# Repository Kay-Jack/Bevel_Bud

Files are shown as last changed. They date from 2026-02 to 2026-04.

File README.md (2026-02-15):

# Bezel_Bud
Take a webcam -> remove the camera -> improve the microphone.

- **Status:** Prototype Dev Board
- **Author:** Jack Kay

## Features

- **Feature 1:** 48KHz Dual Microphone - TI PCM1861
- **Feature 2:** Low noise components
- **Feature 3:** Power filtering
- **Feature 4:** 24.576MHz Crystal
- **Feature 5:** Mute switch and Visual LED
- **Feature 6:** Configurable jumpers for ADC
- **Feature 7:** USB-C for connectivity
- **Feature 8:** STM32G431CBT6

## Photos

### Assembly PCB

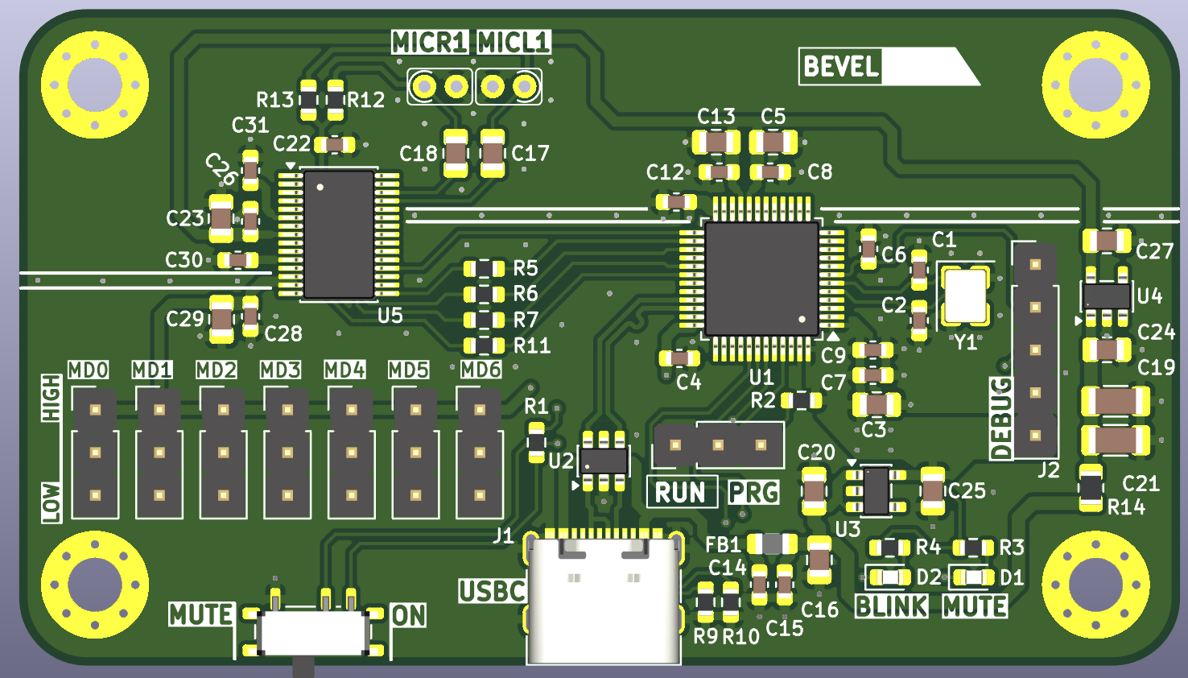
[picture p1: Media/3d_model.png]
3D model


### Layout

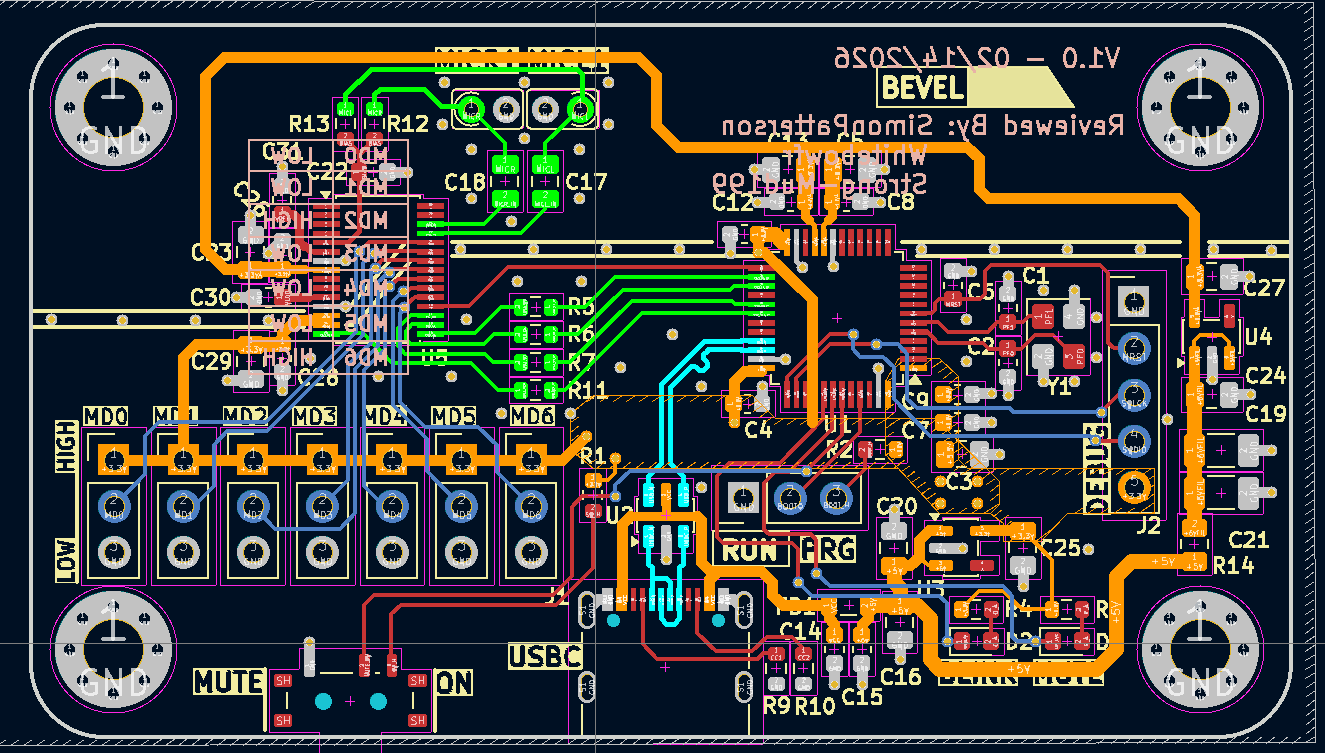
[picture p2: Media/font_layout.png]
Font layout


### Schematic

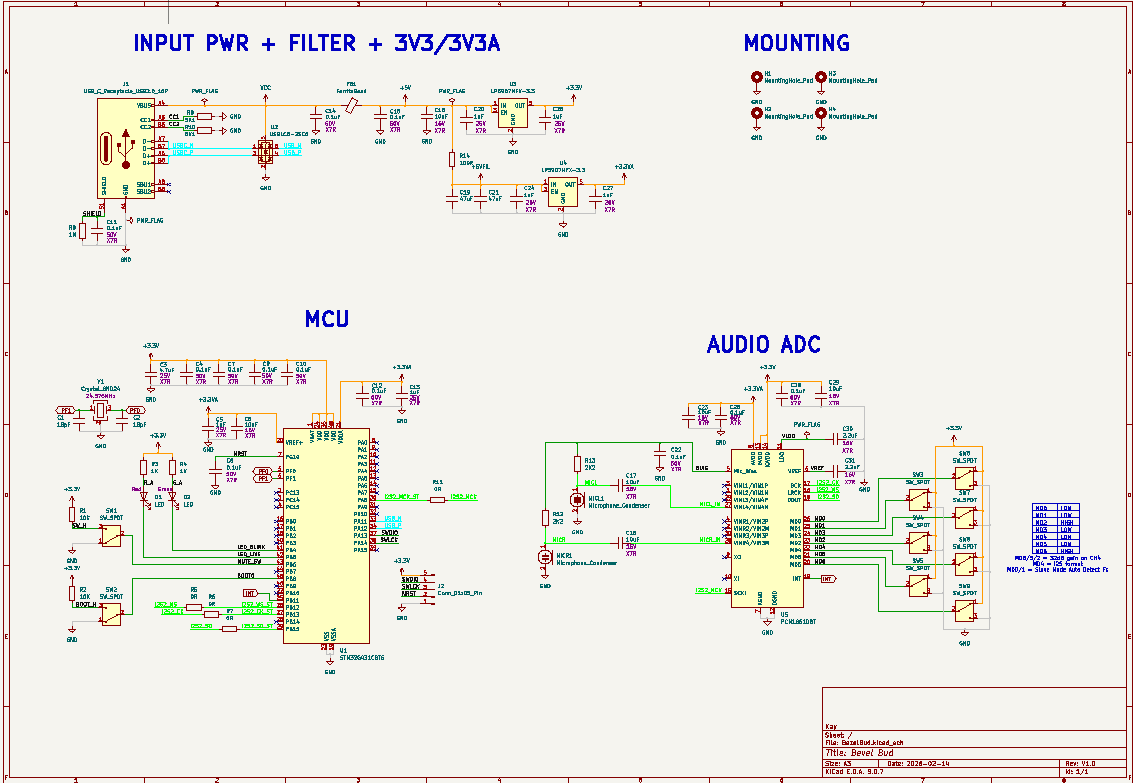
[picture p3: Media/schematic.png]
Schematic


## Firmware / Electronics

[WIP]

## CAD / Mechanical

[WIP]

## Build Instructions

[WIP]

## Usage

[WIP]

## License

This project is licensed under the terms in the `LICENSE` file.

## Contact

Maintainer: Jack Kay — jack.wil.kay@gmail.com

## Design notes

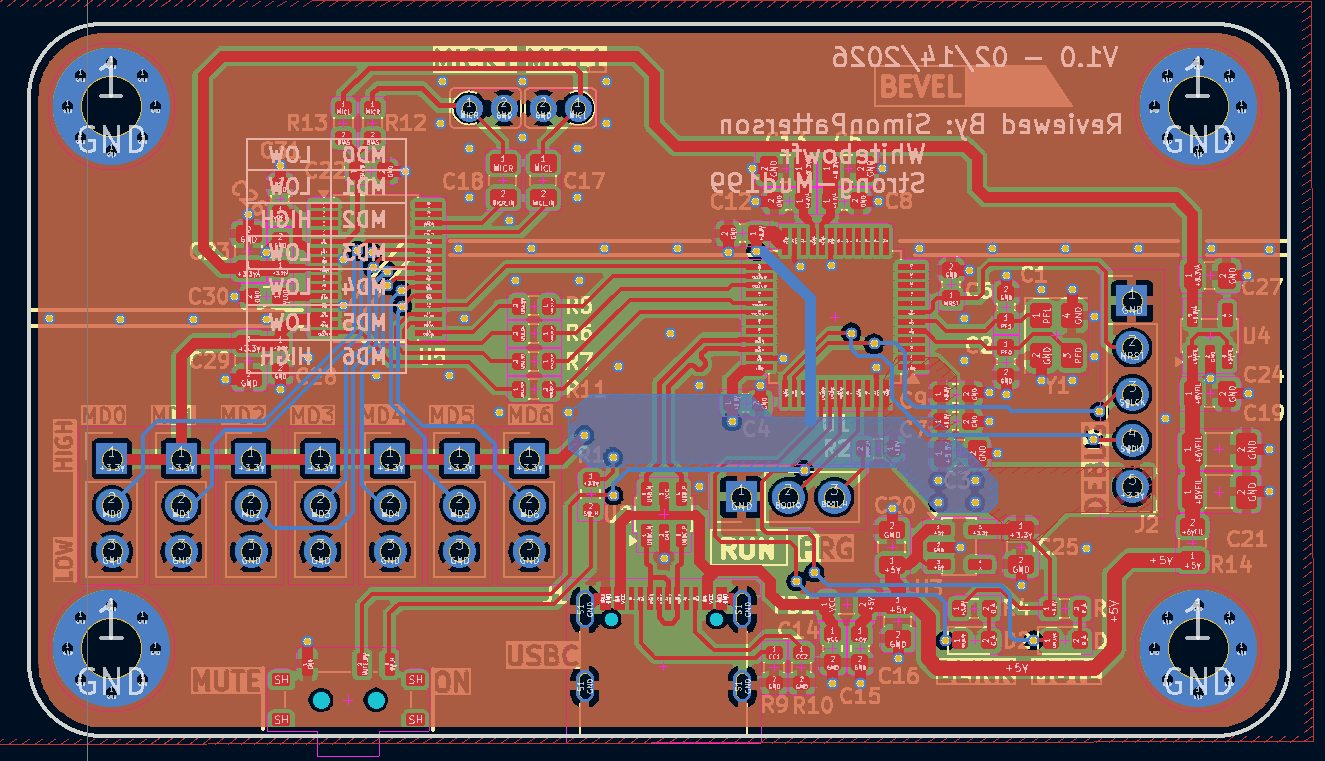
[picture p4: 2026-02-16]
Media/font_layout_trad_filled.png

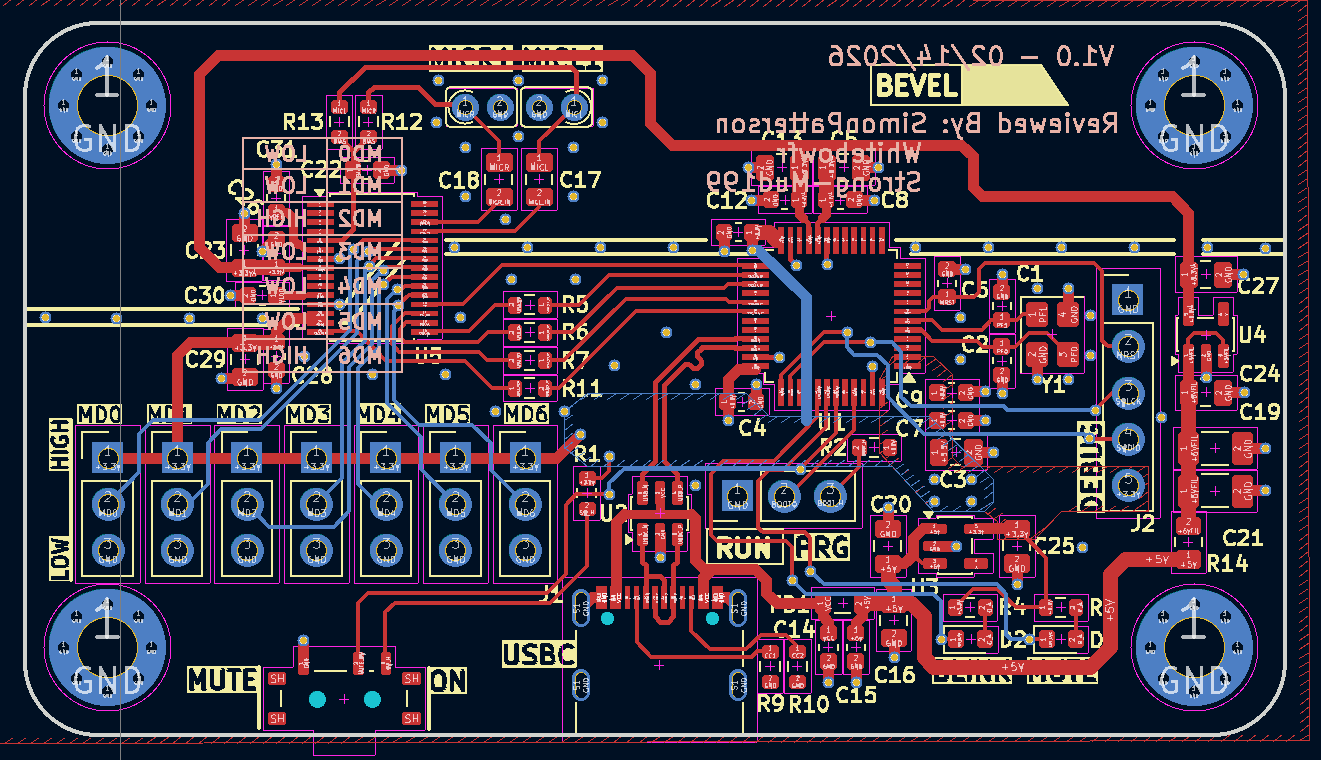
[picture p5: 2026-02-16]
Media/font_layout_trad.png

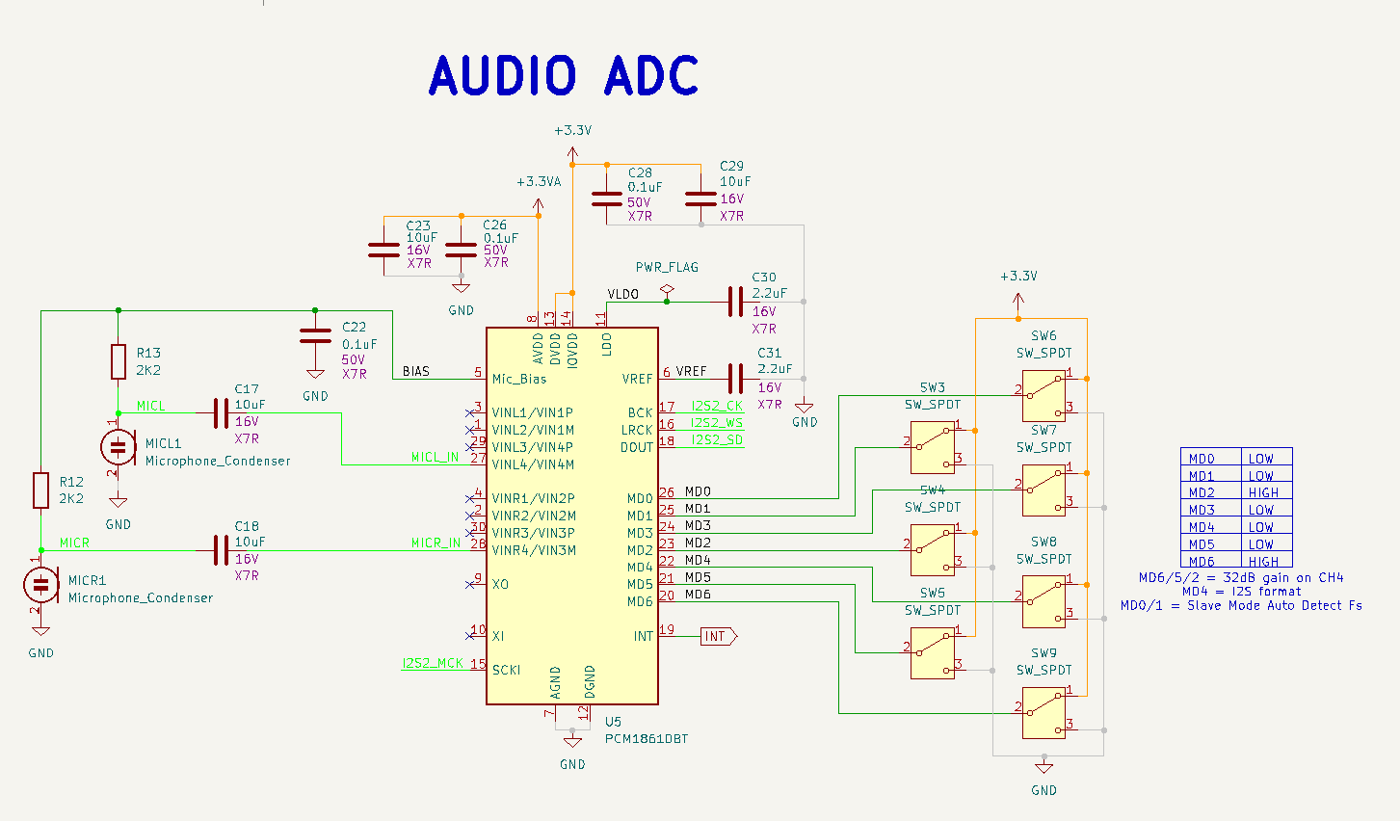
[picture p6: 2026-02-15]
Media/audio_schem.png

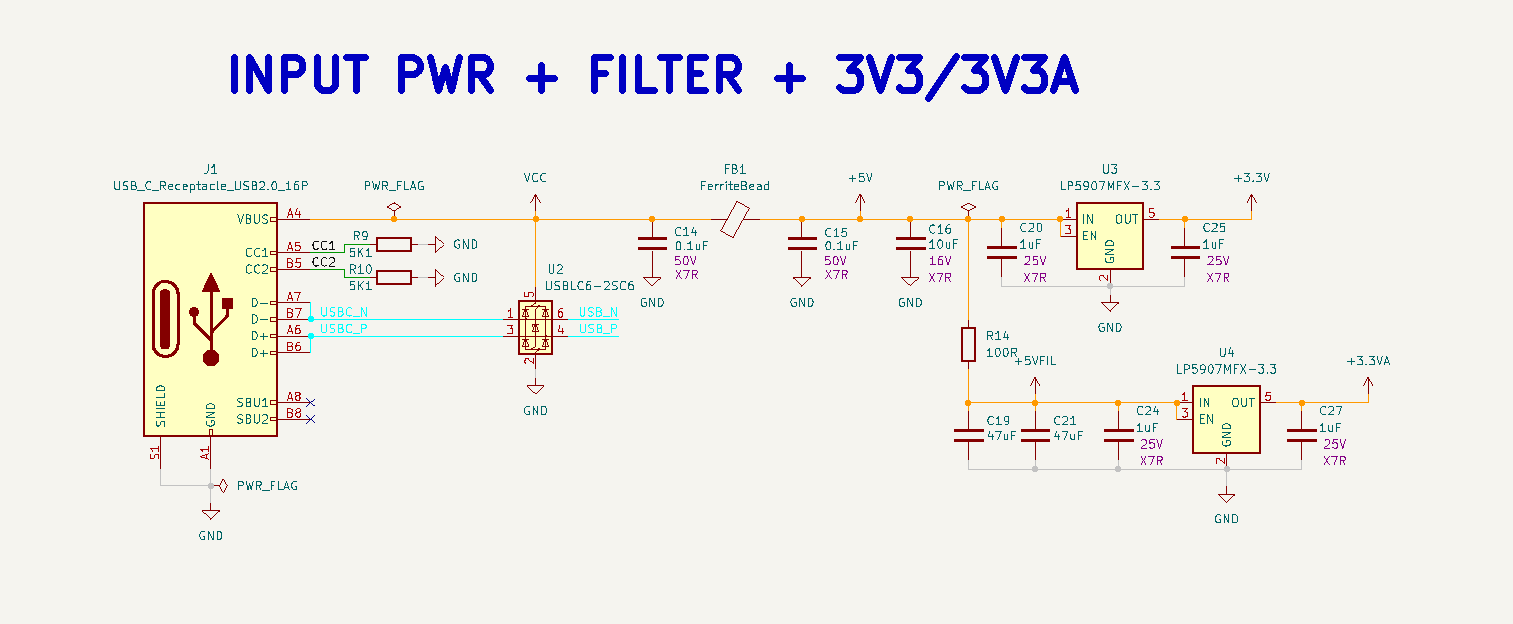
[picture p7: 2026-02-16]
Media/pwr_schem.png

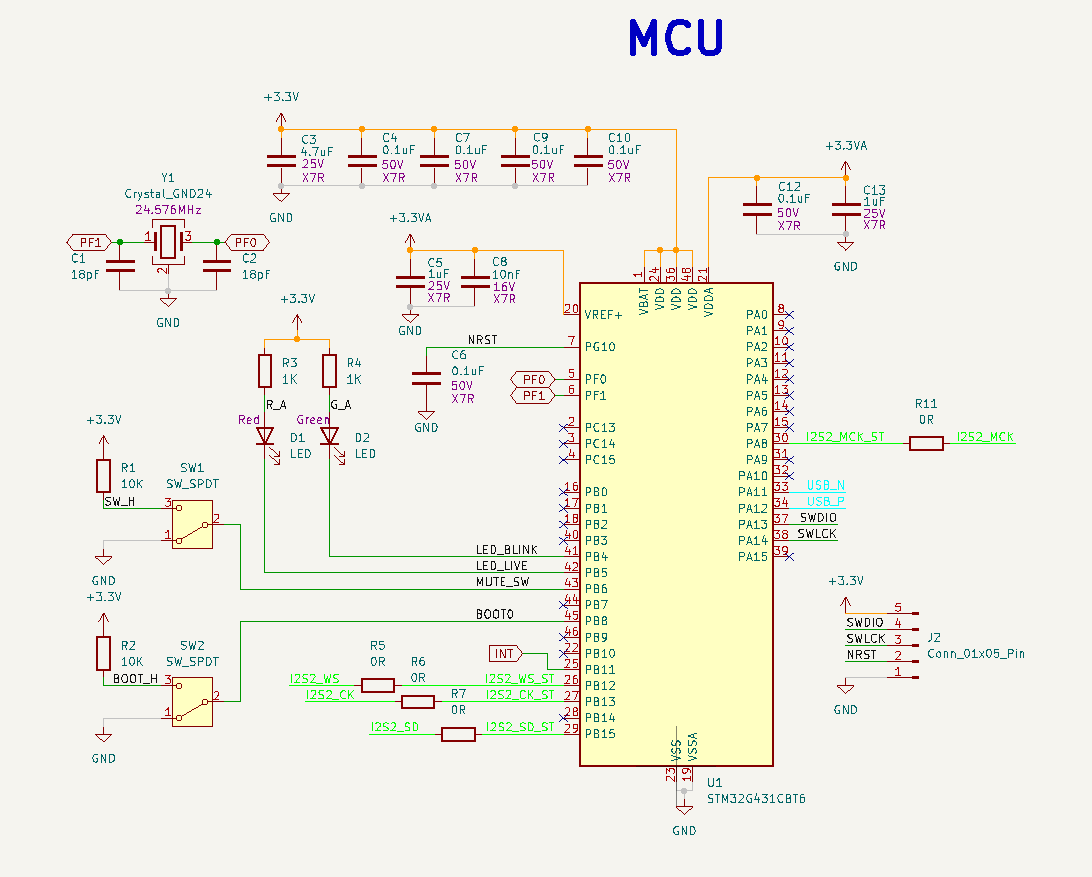
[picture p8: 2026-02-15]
Media/mcu_schem.png

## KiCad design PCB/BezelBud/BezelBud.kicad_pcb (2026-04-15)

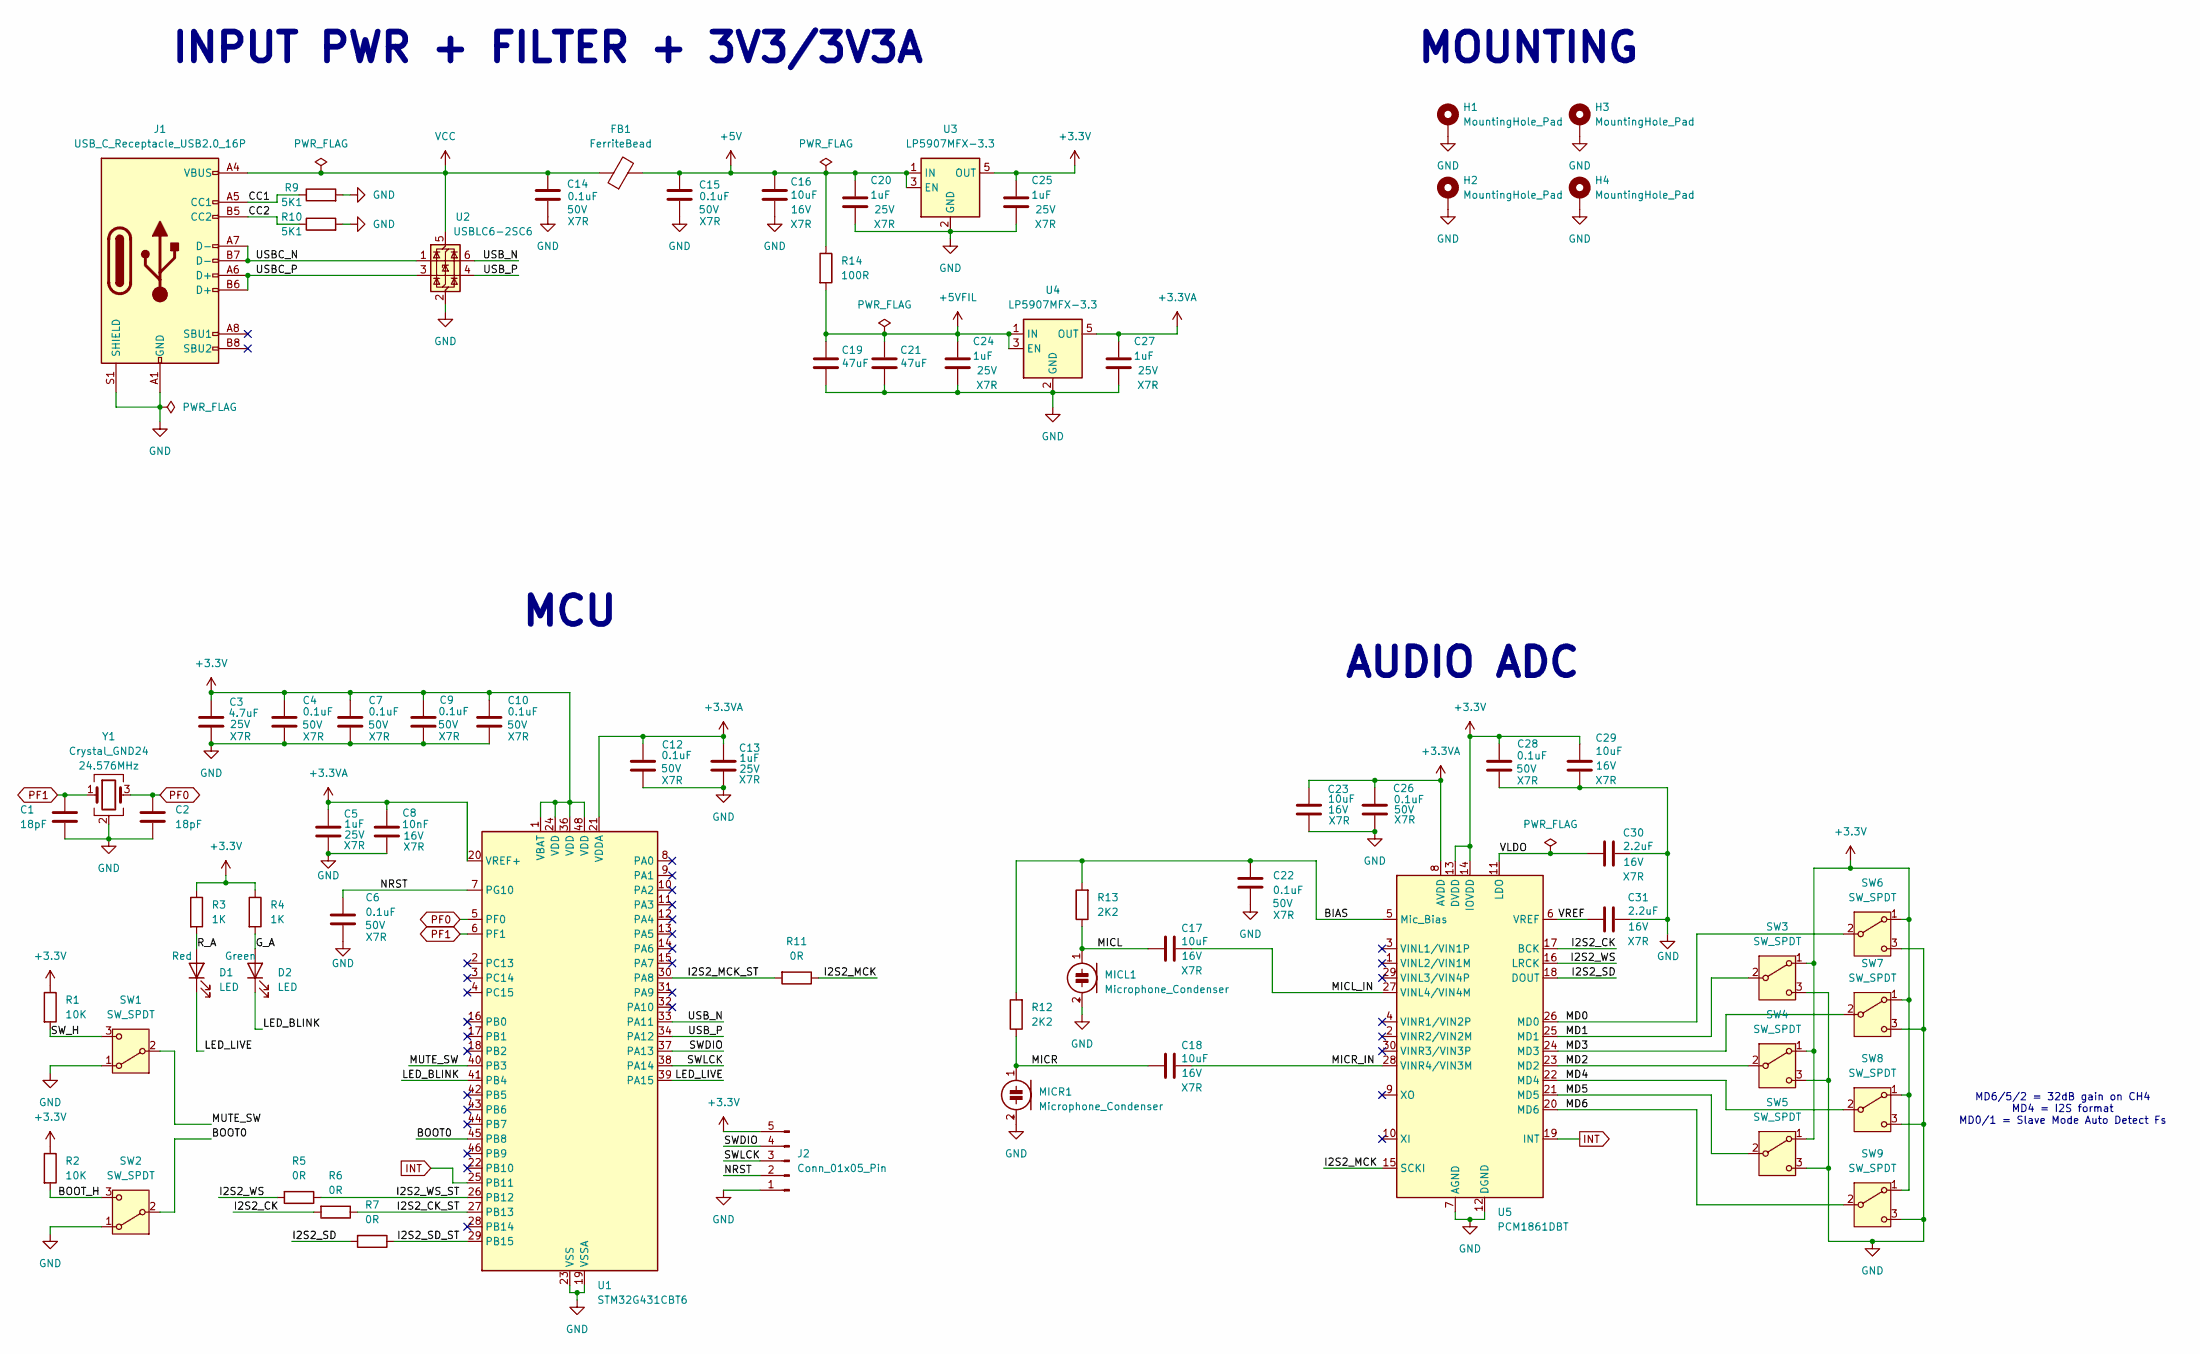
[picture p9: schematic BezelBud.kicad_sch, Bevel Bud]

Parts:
C1, C2: 18pF; C_0603_1608Metric
C3: 4.7uF; C_0805_2012Metric; Voltage 25V; Rating X7R
C4, C6, C7, C9, C10, C12, C14, C15, C22, C26, C28: 0.1uF; C_0603_1608Metric; Voltage 50V; Rating X7R
C5, C13, C20, C24, C25, C27: 1uF; C_0805_2012Metric; Voltage 25V; Rating X7R
C8: 10nF; C_0603_1608Metric; Rating X7R; Voltage 16V
C16, C17, C18, C23, C29: 10uF; C_0805_2012Metric; Voltage 16V; Rating X7R
C19: 47uF; C_1206_3216Metric; Voltage 10V; Rating X5R
C21: 47uF; C_1206_3216Metric; Voltage 16V; Rating X5R
C30, C31: 2.2uF; C_0603_1608Metric; Voltage 16V; Rating X7R
D1, D2: LED; LED_0603_1608Metric
FB1: FerriteBead; L_0805_2012Metric
H1, H2, H3, H4: MountingHole_Pad; MountingHole_3.2mm_M3_Pad_Via
J1: USB_C_Receptacle_USB2.0_16P; USB_C_Receptacle_G-Switch_GT-USB-7010ASV
J2: Conn_01x05_Pin; PinHeader_1x05_P2.54mm_Vertical
MICL1: Microphone_Condenser; R_Axial_DIN0204_L3.6mm_D1.6mm_P1.90mm_Vertical
MICR1: Microphone_Condenser; R_Axial_DIN0204_L3.6mm_D1.6mm_P1.90mm_Vertical
R1, R2: 10K; R_0603_1608Metric
R3, R4: 1K; R_0603_1608Metric
R5, R6, R7, R11: 0R; R_0603_1608Metric
R9, R10: 5K1; R_0603_1608Metric
R12, R13: 2K2; R_0603_1608Metric
R14: 100R; R_0805_2012Metric
SW1: SW_SPDT; SW_SPDT_Shouhan_MSK12C02
SW2, SW3, SW4, SW5, SW6, SW7, SW8, SW9: SW_SPDT; PinHeader_1x03_P2.54mm_Vertical
U1: STM32G431CBT6; LQFP-48_7x7mm_P0.5mm
U2: USBLC6-2SC6; SOT-23-6
U3, U4: LP5907MFX-3.3; SOT-23-5
U5: PCM1861DBT; TSSOP-30_4.4x7.8mm_P0.5mm
Y1: Crystal_GND24; Crystal_SMD_3225-4Pin_3.2x2.5mm

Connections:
+3.3V: C3.1, C4.1, C7.1, C9.1, C10.1, C25.1, C28.1, C29.1, J2.5, R1.1, R2.1, R3.1, R4.1, SW3.1 (A), SW4.1 (A), SW5.1 (A), SW6.1 (A), SW7.1 (A), SW8.1 (A), SW9.1 (A), U1.1 (VBAT), U1.24 (VDD), U1.36 (VDD), U1.48 (VDD), U3.5 (OUT), U5.13 (DVDD), U5.14 (IOVDD)
+3.3VA: C5.1, C8.1, C12.1, C13.1, C23.1, C26.1, C27.1, U1.20 (VREF+), U1.21 (VDDA), U4.5 (OUT), U5.8 (AVDD)
+5V: C15.1, C16.1, C20.1, FB1.2, R14.1, U3.1 (IN), U3.3 (EN)
+5VFIL: C19.1, C21.1, C24.1, R14.2, U4.1 (IN), U4.3 (EN)
/BIAS: C22.1, R12.2, R13.2, U5.5 (Mic_Bias)
/BOOT0: SW2.2 (B), U1.45 (PB8)
/BOOT_H: R2.2, SW2.3 (C)
/CC1: J1.A5 (CC1), R9.1
/CC2: J1.B5 (CC2), R10.1
/G_A: D2.2 (A), R4.2
/I2S2_CK: R6.2, U5.17 (BCK)
/I2S2_CK_ST: R6.1, U1.27 (PB13)
/I2S2_MCK: R11.1, U5.15 (SCKI)
/I2S2_MCK_ST: R11.2, U1.30 (PA8)
/I2S2_SD: R7.2, U5.18 (DOUT)
/I2S2_SD_ST: R7.1, U1.29 (PB15)
/I2S2_WS: R5.2, U5.16 (LRCK)
/I2S2_WS_ST: R5.1, U1.26 (PB12)
/LED_BLINK: D2.1 (K), U1.41 (PB4)
/LED_LIVE: D1.1 (K), U1.39 (PA15)
/MD0: SW6.2 (B), U5.26 (MD0)
/MD1: SW3.2 (B), U5.25 (MD1)
/MD2: SW4.2 (B), U5.23 (MD2)
/MD3: SW7.2 (B), U5.24 (MD3)
/MD4: SW8.2 (B), U5.22 (MD4)
/MD5: SW5.2 (B), U5.21 (MD5)
/MD6: SW9.2 (B), U5.20 (MD6)
/MICL: C17.1, MICL1.1 (-), R13.1
/MICL_IN: C17.2, U5.27 (VINL4/VIN4M)
/MICR: C18.1, MICR1.1 (-), R12.1
/MICR_IN: C18.2, U5.28 (VINR4/VIN3M)
/MUTE_SW: SW1.2 (B), U1.40 (PB3)
/NRST: C6.1, J2.2, U1.7 (PG10)
/R_A: D1.2 (A), R3.2
/SWDIO: J2.4, U1.37 (PA13)
/SWLCK: J2.3, U1.38 (PA14)
/SW_H: R1.2, SW1.3 (C)
/USBC_N: J1.A7 (D-), J1.B7 (D-), U2.1 (I/O1)
/USBC_P: J1.A6 (D+), J1.B6 (D+), U2.3 (I/O2)
/USB_N: U1.33 (PA11), U2.6 (I/O1)
/USB_P: U1.34 (PA12), U2.4 (I/O2)
/VLDO: C30.1, U5.11 (LDO)
/VREF: C31.1, U5.6 (VREF)
GND: C1.2, C2.2, C3.2, C4.2, C5.2, C6.2, C7.2, C8.2, C9.2, C10.2, C12.2, C13.2, C14.2, C15.2, C16.2, C19.2, C20.2, C21.2, C22.2, C23.2, C24.2, C25.2, C26.2, C27.2, C28.2, C29.2, C30.2, C31.2, H1.1, H2.1, H3.1, H4.1, J1.A1 (GND), J1.A12 (GND), J1.B1 (GND), J1.B12 (GND), J1.S1 (SHIELD), J2.1, MICL1.2 (+), MICR1.2 (+), R9.2, R10.2, SW1.1 (A), SW2.1 (A), SW3.3 (C), SW4.3 (C), SW5.3 (C), SW6.3 (C), SW7.3 (C), SW8.3 (C), SW9.3 (C), U1.19 (VSSA), U1.23 (VSS), U1.35 (VSS), U1.47 (VSS), U2.2 (GND), U3.2 (GND), U4.2 (GND), U5.7 (AGND), U5.12 (DGND), Y1.2 (G), Y1.4 (G)
INT: U1.25 (PB11), U5.19 (INT)
PF0: C2.1, U1.5 (PF0), Y1.3
PF1: C1.1, U1.6 (PF1), Y1.1
VCC: C14.1, FB1.1, J1.A4 (VBUS), J1.A9 (VBUS), J1.B4 (VBUS), J1.B9 (VBUS), U2.5 (VBUS)

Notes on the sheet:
MCU
AUDIO ADC
MD6/5/2 = 32dB gain on CH4 MD4 = I2S format MD0/1 = Slave Mode Auto Detect Fs
MOUNTING
INPUT PWR + FILTER + 3V3/3V3A

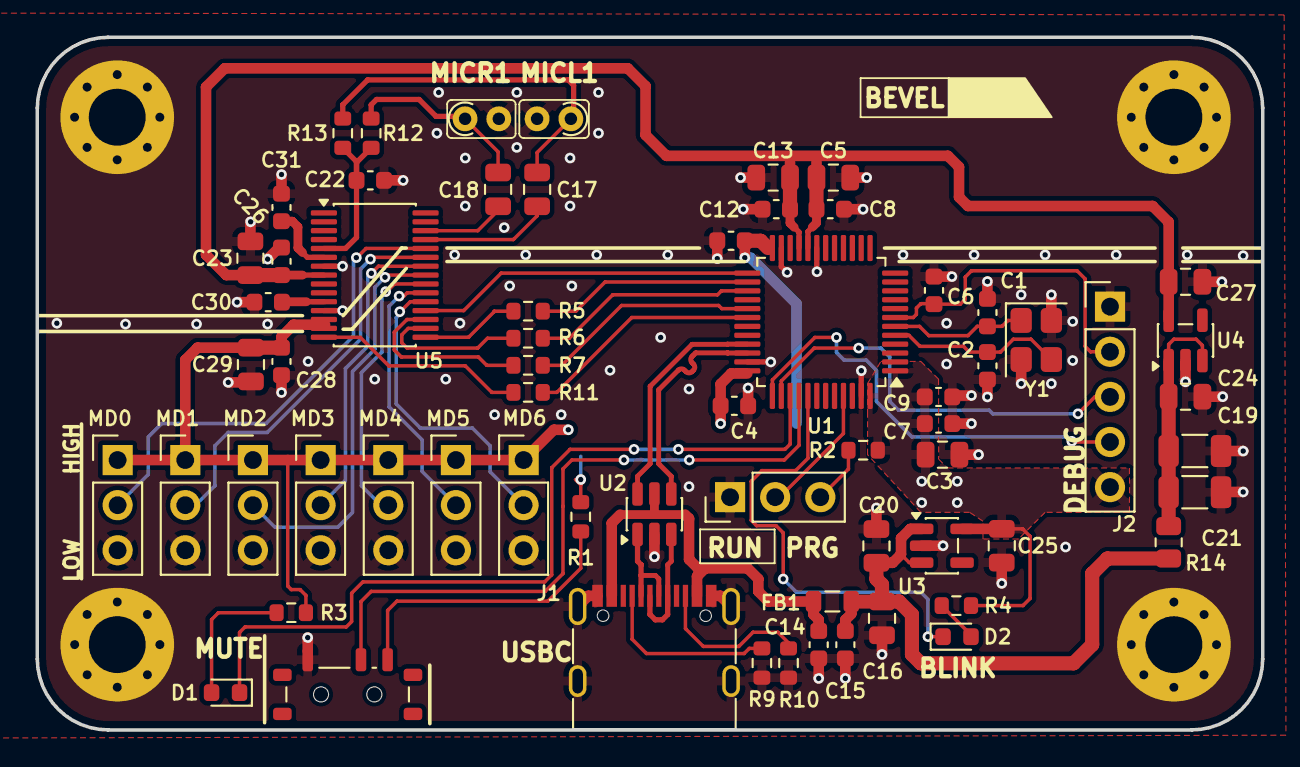
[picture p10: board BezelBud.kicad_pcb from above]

Board: 4 copper layers, 69.0 x 39.0 mm, 69 parts (0 on the bottom side), 48 nets.

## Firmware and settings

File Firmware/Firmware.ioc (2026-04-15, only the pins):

Mcu.UserName=STM32G431CBTx
PA11.Signal=USB_DM
PA12.Signal=USB_DP
PA13.Signal=SYS_JTMS-SWDIO
PA14.Signal=SYS_JTCK-SWCLK
PA15.GPIO_Label=LED_LIVE
PA15.Signal=GPIO_Output
PA8.Signal=I2S2_MCK
PB11.GPIO_Label=INTRPT
PB11.Signal=GPIO_Input
PB12.Signal=I2S2_WS
PB13.Signal=I2S2_CK
PB15.Signal=I2S2_SD
PB3.GPIO_Label=MUTE_SW
PB3.Signal=GPIO_Input
PB4.GPIO_Label=LED_BLINK
PB4.Signal=GPIO_Output
PB8-BOOT0.GPIO_Label=Boot0
PB8-BOOT0.Signal=GPIO_Output
PF0-OSC_IN.Signal=RCC_OSC_IN
PF1-OSC_OUT.Signal=RCC_OSC_OUT

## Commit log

2026-01-30 Initialized PCB and STM32Cube
    [BezelBud.kicad_pcb, BezelBud.kicad_sch]
2026-02-02 Added parts to schematic
    [BezelBud.kicad_sch]
2026-02-05 updated firmware and schematic
    [BezelBud.kicad_sch]
2026-02-10 Finalized component selection
    Selected caps, ratings and footprints. Added crystal to codec
    Added Interrupt
    Wired master clk as backup
    updated cubeMX to match
    [BezelBud.kicad_sch]
2026-02-10 Added Footprint for Crystal and Microphone
    [BezelBud.kicad_sch]
2026-02-12 Numerous quality of life changes and started PCB Design
    - Configuration pins
    - 16P USBC
    - Removed Microphone pads, will be using a small 2 pin pad for now
    - reduced part count if possible
    [BezelBud.kicad_pcb, BezelBud.kicad_sch]
2026-02-12 Swapped MCU to M4 need to update schematic
    [BezelBud.kicad_sch]
2026-02-13 small updates to schematic and layout for new stm32
    [BezelBud.kicad_pcb, BezelBud.kicad_sch]
2026-02-13 updated pcb layout
    [BezelBud.kicad_pcb, BezelBud.kicad_sch]
2026-02-14 Updated PCB
    [BezelBud.kicad_pcb, BezelBud.kicad_sch]
2026-02-14 Added bleed resistor and cap to shield <> GND con
    [BezelBud.kicad_pcb, BezelBud.kicad_sch]
2026-02-15 updated layout picture
    [BezelBud.kicad_pcb]
2026-02-15 remapped int pin to avoid crossing
    [BezelBud.kicad_pcb, BezelBud.kicad_sch]
2026-02-15 saved schem
    [BezelBud.kicad_sch]
2026-02-15 removed usb decoupling and moved blink and led vias
    [BezelBud-B_Cu.gbr, BezelBud-B_Gnd.gbr, BezelBud-B_Mask.gbr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]
2026-02-15 updated size of pcb to be round numbers
    [BezelBud-B_Cu.gbr, BezelBud-B_Gnd.gbr, BezelBud-B_Mask.gbr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]
2026-04-15 Moved Led by switch, moved mute led and mute switch to closer pin
    [BezelBud.kicad_pcb, BezelBud.kicad_sch]
2026-04-15 added suppliers for some parts
    [BezelBud.kicad_pcb, BezelBud.kicad_sch]
